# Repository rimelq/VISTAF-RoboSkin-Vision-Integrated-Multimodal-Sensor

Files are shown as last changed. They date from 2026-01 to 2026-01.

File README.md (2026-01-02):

# VISTAF RoboSkin: Vision-Integrated Multimodal Sensing

**_Robotics Semester Project, CREATE Lab, EPFL_**

A compact vision-based soft sensing skin that jointly estimates **force**, **shape**, and **temperature** from a single RGB camera view.

- **Student**: Rim El Qabli (Robotics MSc, EPFL)
- **Supervisor**: Benhui Dai (CREATE Lab, EPFL)
- **Professor**: Josie Hughes (CREATE Lab, EPFL)

For detailed methodology, fabrication procedures, and complete calibration results, see the full project report in the repo.

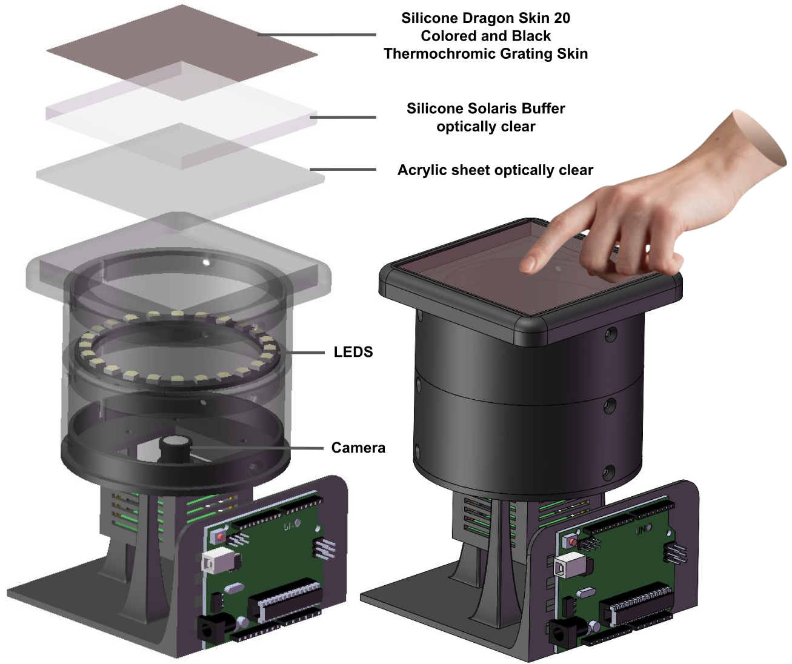
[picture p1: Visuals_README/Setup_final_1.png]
System Overview


## Overview

VISTAF RoboSkin uses a thin (0.6 mm) silicone grating with embedded thermochromic liquid crystal (TLC) pigments. The system combines:

- **Fourier Transform Profilometry (FTP)** for deformation/shape recovery
- **CIELAB-based regression** for temperature inference from TLC color changes
- **Two-stripe design** (colored + black TLC) for both high sensitivity and broad range coverage

This enables dense depth/force and temperature maps without electronics embedded in the skin.

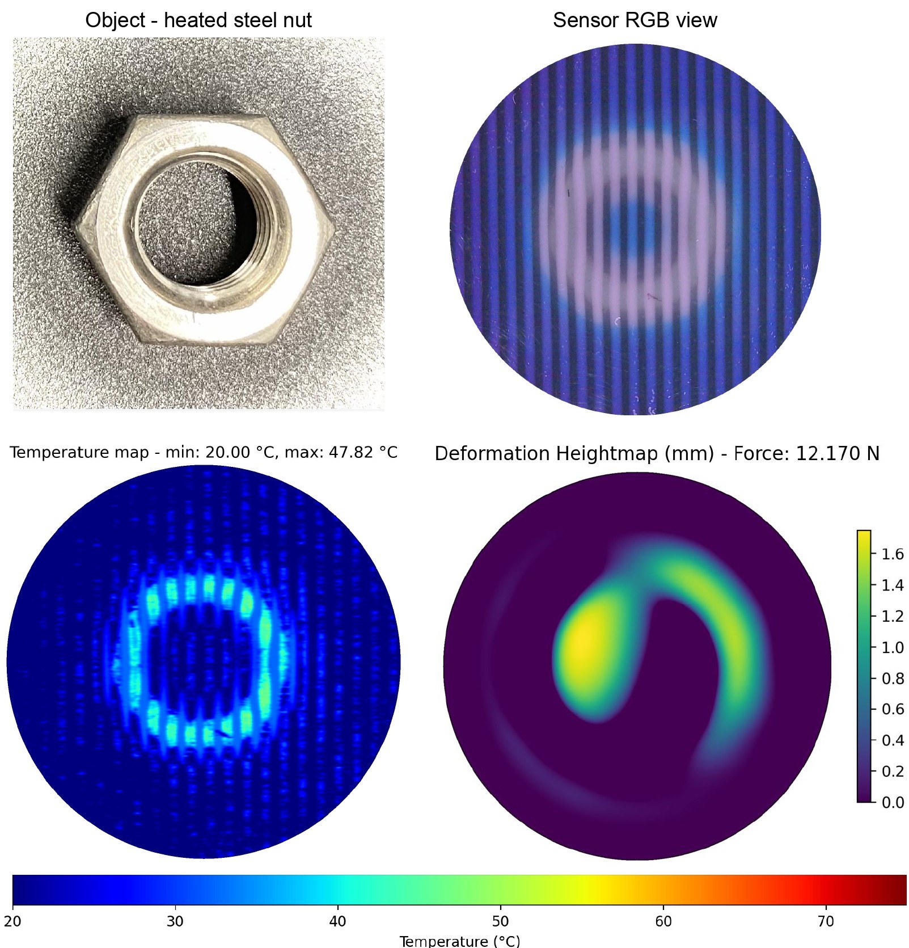
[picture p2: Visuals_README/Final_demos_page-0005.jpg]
Multimodal Demo

*Demo: A heated object pressed into the sensor reconstructs deformation (heightmap + force) and temperature (colormap).*

## How It Works

**Force/Shape Pipeline:**
1. FTP extracts phase differences between reference and deformed grating images
2. Phase → depth conversion via saturating calibration model
3. Depth integration → volume → force via exponential model

**Temperature Pipeline:**
1. CIELAB color feature extraction from TLC appearance
2. Stripe segmentation (colored vs black gratings)
3. Polynomial regression: CIELAB → Temperature

**Multimodal Integration:**
- Single camera view captures both grating deformation and TLC color
- Two stripe populations (colored: high sensitivity 20-33°C, black: broad range 10-75°C)
- Design preserves grayscale contrast for FTP while maximizing thermal information

## Performance Summary

| Module | Metric |
|---|---|
| Phase → Height | RMSE = 2.17 × 10⁻³ mm |
| Volume → Force | RMSE = 6.96 N |
| Temperature (Colored TLC) | RMSE = 0.44 °C |
| Temperature (Black TLC) | RMSE = 1.93 °C |

## Quick Start

### Installation
```bash
# Clone the repository
git clone https://github.com/YOUR_USERNAME/vistaf-roboskin.git
cd vistaf-roboskin

# Install dependencies
pip install numpy opencv-python matplotlib scikit-image scikit-learn scipy joblib
```

## Repository Structure
```
├── CAD/                              # CAD files for the setup
├── Code/                             # All source code (Python + notebooks)
│   ├── multimodal_sensor.py          # Main entry point (run multimodal inference)
│   ├── force_sensor.py               # Force sensing module
│   ├── temperature_sensor.py         # Temperature sensing module
│   ├── shape_ftp.py                  # FTP core pipeline
│   ├── phase_to_height.py            # Phase→height calibration
│   ├── height_to_force.py            # Height/volume→force calibration
│   ├── temperature_color_model.py    # Colored TLC temperature calibration
│   ├── temperature_black_model.py    # Black TLC temperature calibration
│   ├── pretest_25to30.py             # Temperature pretest (25→30 °C)
│   ├── pretest_30to31.py             # Temperature pretest (30→31 °C)
│   ├── michelson.ipynb               # Michelson contrast / TLC selection notebook
│   └── Arduino LED code/             # Arduino code for LED ring
├── Final_demos_images/               # Demo input images (used in report/README)
├── Force/                            # Force datasets + calibration outputs
├── Temperature/                      # Temperature datasets + calibration outputs
├── Multimodal_Sensor/                # Multimodal run outputs (session folders)
├── Visuals_README/                   # Figures used in README.md
├── camera_config.gpfl                # Camera configuration
├── Rim_El_Qabli_VISTAF_Report.pdf    # Full project report (PDF)
└── README.md                         # This file
```

### Running the Multimodal Sensor

Edit the paths at the top of `multimodal_sensor.py`:
```python
REFERENCE_IMAGE = "./Final_demos_images/FINAL_reference.jpg"
DEFORMED_IMAGE  = "./Final_demos_images/FINAL_ROUND_METAL.jpg"
OUTPUT_ROOT     = "./Multimodal_Sensor/run_output"

# Optional: Show interactive 3D heightmap window
SHOW_3D_HEIGHTMAP_INTERACTIVE = True
```

```bash
python multimodal_sensor.py
```

This will:
1. Load a reference image (no contact) and a deformed image (with contact/heating)
2. Run FTP to compute shape and force
3. Run temperature inference on the deformed image
4. Generate combined outputs with visualizations
5. Save results to `./Multimodal_Sensor/run_output/session_TIMESTAMP/`

### Outputs

After running, the session folder contains:
```
session_TIMESTAMP/
├── force_sensing/
│   └── ftp_run/                    # FTP heightmaps and debug figures
├── temperature_sensing/
│   ├── temperature_map_final_colormap.png
│   └── temperature_map_final.npy
├── combined_outputs/
│   ├── multimodal_summary.json     # Complete results + calibration metrics
│   ├── force_shape_heightmap.png   # Heightmap with force annotation
│   └── temp_*.png                  # Temperature visualizations
```

The `multimodal_summary.json` includes:
- Force estimate (N), volume (cm³), contact area (mm²), max depth (mm)
- Temperature statistics (mean, median, std, min/max)
- All calibration model equations and performance metrics

## Contact

- **Rim El Qabli**: rim.elqabli@epfl.ch
- **CREATE Lab**: https://www.epfl.ch/labs/create-lab/

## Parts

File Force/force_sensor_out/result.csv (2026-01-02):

reference_path | deformed_path | volume_cm3 | force_N | contact_area_mm2 | max_depth_mm | mm_per_px | estimated_grating_period_px | ftp_output_dir | force_model_type
./Force/FINAL_reference.jpg | ./Force/Final_demos/FFFFF_deformed.jpg | 0.15452928236587474 | 5.695553435044693 | 271.75127834004024 | 1.5117931365966797 | 0.030378426119953176 | 65.83619546657023 | ./Force/force_sensor_out/ftp_run | growth

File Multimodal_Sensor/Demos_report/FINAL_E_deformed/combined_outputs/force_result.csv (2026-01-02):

reference_path | deformed_path | volume_cm3 | force_N | contact_area_mm2 | max_depth_mm | mm_per_px | estimated_grating_period_px | ftp_output_dir | force_model_type
./Force/FINAL_reference.jpg | ./Final_demos_images/FINAL_E_deformed.jpg | 0.11378655442935222 | 3.2960528395288056 | 304.914771865451 | 1.1214957237243652 | 0.030378426119953176 | 65.83619546657023 | ./Multimodal_Sensor/run_output/session_20260101_195039/force_sensing/ftp_run | growth

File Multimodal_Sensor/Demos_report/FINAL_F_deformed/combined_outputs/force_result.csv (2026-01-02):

reference_path | deformed_path | volume_cm3 | force_N | contact_area_mm2 | max_depth_mm | mm_per_px | estimated_grating_period_px | ftp_output_dir | force_model_type
./Force/FINAL_reference.jpg | ./Final_demos_images/FINAL_F_deformed.jpg | 0.15452928236587474 | 5.695553435044693 | 271.75127834004024 | 1.5117931365966797 | 0.030378426119953176 | 65.83619546657023 | ./Multimodal_Sensor/run_output/session_20260101_194957/force_sensing/ftp_run | growth

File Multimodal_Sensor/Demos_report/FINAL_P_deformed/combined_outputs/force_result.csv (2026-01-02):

reference_path | deformed_path | volume_cm3 | force_N | contact_area_mm2 | max_depth_mm | mm_per_px | estimated_grating_period_px | ftp_output_dir | force_model_type
./Force/FINAL_reference.jpg | ./Final_demos_images/FINAL_P_deformed.jpg | 0.09709512564796216 | 2.557286790972208 | 327.0289970254414 | 0.9775881767272949 | 0.030378426119953176 | 65.83619546657023 | ./Multimodal_Sensor/run_output/session_20260101_194609/force_sensing/ftp_run | growth

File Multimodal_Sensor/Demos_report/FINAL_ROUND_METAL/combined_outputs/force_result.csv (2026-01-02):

reference_path | deformed_path | volume_cm3 | force_N | contact_area_mm2 | max_depth_mm | mm_per_px | estimated_grating_period_px | ftp_output_dir | force_model_type
./Force/FINAL_reference.jpg | ./Final_demos_images/FINAL_ROUND_METAL.jpg | 0.21950436806104176 | 12.169759841071881 | 343.2434499762836 | 1.7482119798660278 | 0.030378426119953176 | 65.83619546657023 | ./Multimodal_Sensor/run_output/session_20260101_195157/force_sensing/ftp_run | growth

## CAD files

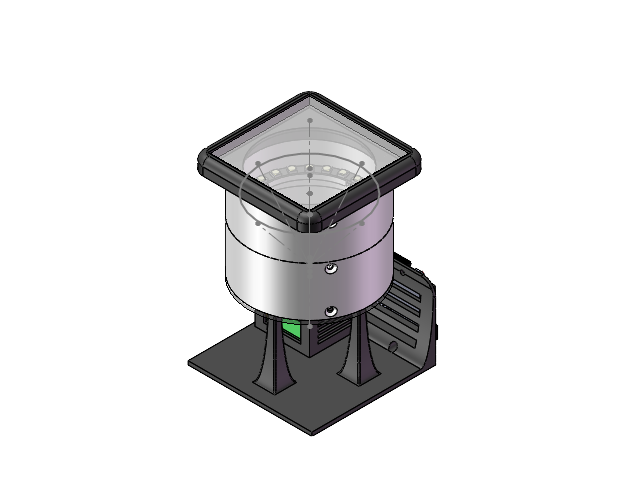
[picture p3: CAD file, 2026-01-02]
CAD/v2-setup.SLDASM
v2-top base
v2-middle holder
v2-led light ring
v2-bottom base
camera
arcylic layer
transparent elastic layer
v2-adjust base
v2-camera connect
test support
arduino uno

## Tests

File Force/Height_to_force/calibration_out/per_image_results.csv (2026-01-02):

file | force_N | volume_cm3 | contact_area_mm2 | max_depth_mm | mm_per_px | estimated_grating_period_px | ftp_output_dir
sphere-1.jpg | 0.5 | 0.013897318468323634 | 205.22311025659033 | 0.2618858516216278 | 0.030378426119953176 | 65.83619546657023 | ./Force/Height_to_force/calibration_out/ftp_runs/001_sphere-1_F0.5N
sphere-2.jpg | 0.5 | 0.015697668452302027 | 206.68121131876055 | 0.22853468358516693 | 0.030378426119953176 | 65.83619546657023 | ./Force/Height_to_force/calibration_out/ftp_runs/002_sphere-2_F0.5N
sphere-3.jpg | 0.5 | 0.010988610885390073 | 161.01034836575937 | 0.20464380085468292 | 0.030378426119953176 | 65.83619546657023 | ./Force/Height_to_force/calibration_out/ftp_runs/003_sphere-3_F0.5N
sphere-4.jpg | 0.5 | 0.019896585310867573 | 267.0484409901546 | 0.25566136837005615 | 0.030378426119953176 | 65.83619546657023 | ./Force/Height_to_force/calibration_out/ftp_runs/004_sphere-4_F0.5N
sphere-5.jpg | 0.5 | 0.010413515682411756 | 161.8335294717441 | 0.16386406123638153 | 0.030378426119953176 | 65.83619546657023 | ./Force/Height_to_force/calibration_out/ftp_runs/005_sphere-5_F0.5N
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

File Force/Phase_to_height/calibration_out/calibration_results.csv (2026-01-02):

file | depth_mm | min_height_unitless | min_x | min_y | heightmap_figure
Height_0.5mm_deformed.jpg | 1.90935 | -0.5882240533828735 | 703 | 514 | Height_0.5mm_deformed/heightmap.png
Height_1mm_deformed.jpg | 1.9477 | -0.6571923494338989 | 607 | 524 | Height_1mm_deformed/heightmap.png
Height_1.5mm_deformed.jpg | 2.01821 | -0.8232495188713074 | 729 | 537 | Height_1.5mm_deformed/heightmap.png
Height_2mm_deformed.jpg | 2.07255 | -1.2602728605270386 | 722 | 588 | Height_2mm_deformed/heightmap.png

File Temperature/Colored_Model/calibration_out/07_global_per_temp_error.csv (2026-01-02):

label | T_true | n_frames | mean_pred | mean_err | mae | rmse | max_abs_err
global | 20.0 | 10 | 20.186666666666664 | 0.18666666666666706 | 0.18666666666666706 | 0.3412395704551935 | 0.6666666666666679
global | 21.0 | 10 | 20.813333333333333 | -0.186666666666666 | 0.186666666666666 | 0.2649947588580229 | 0.3999999999999986
global | 22.0 | 10 | 22.25 | 0.25 | 0.25 | 0.3535533905932738 | 0.5
global | 23.0 | 10 | 23.375 | 0.375 | 0.875 | 0.9519716382329886 | 1.25
global | 24.0 | 10 | 24.25 | 0.25 | 0.25 | 0.25 | 0.25
global | 25.0 | 10 | 25.5 | 0.5 | 0.5 | 0.7071067811865476 | 1.0
global | 26.0 | 10 | 25.375 | -0.625 | 1.125 | 1.286953767623375 | 1.75
global | 27.0 | 10 | 26.25 | -0.75 | 0.75 | 0.7905694150420949 | 1.0
global | 28.0 | 10 | 28.0 | 0.0 | 0.0 | 0.0 | 0.0
global | 29.0 | 10 | 29.800000000000004 | 0.8000000000000007 | 0.8000000000000007 | 1.1313708498984771 | 1.6000000000000014
global | 30.0 | 10 | 30.300000000000004 | 0.3000000000000007 | 0.3000000000000007 | 0.4242640687119295 | 0.6000000000000014
global | 31.0 | 10 | 30.600000000000005 | -0.3999999999999986 | 0.3999999999999986 | 0.3999999999999986 | 0.3999999999999986
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

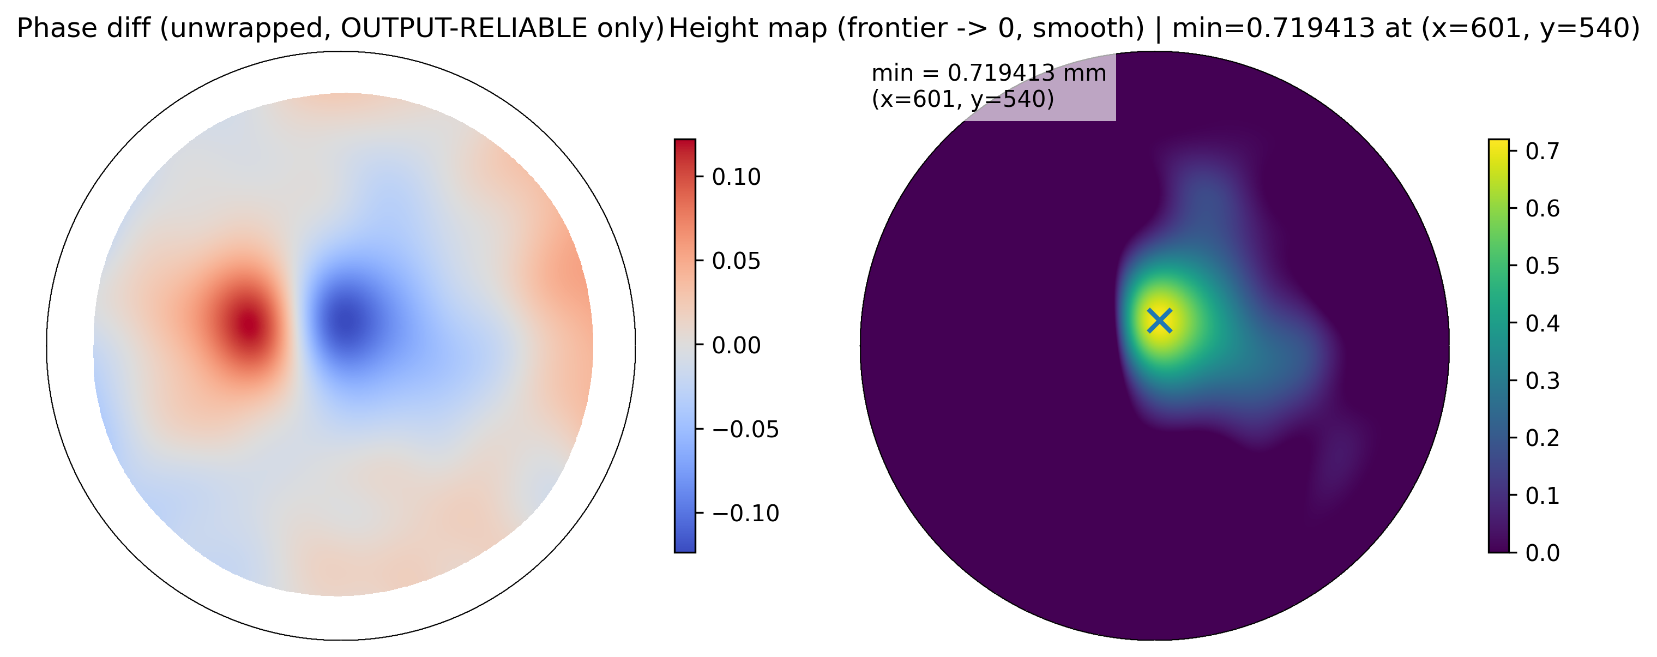
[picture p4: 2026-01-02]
Force/Height_to_force/calibration_out/ftp_runs/008_sphere-8_F1N/07_phase_and_height_FINAL_SMOOTH_ROI.png

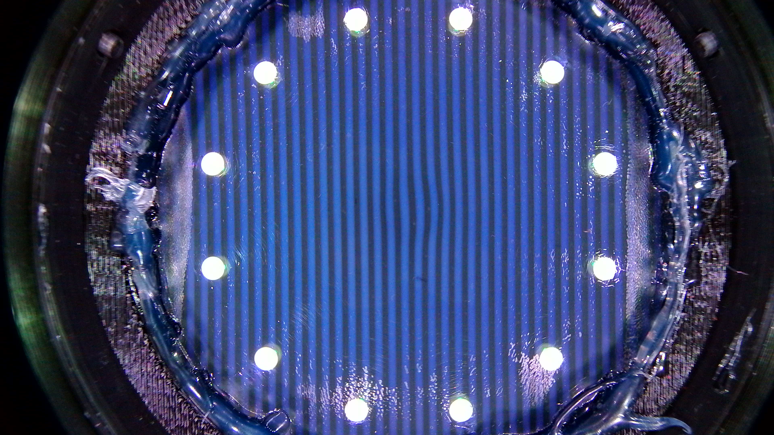
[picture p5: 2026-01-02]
Force/Height_to_force/calibration_out/ftp_runs/039_sphere-39_F10N/sphere-39.jpg

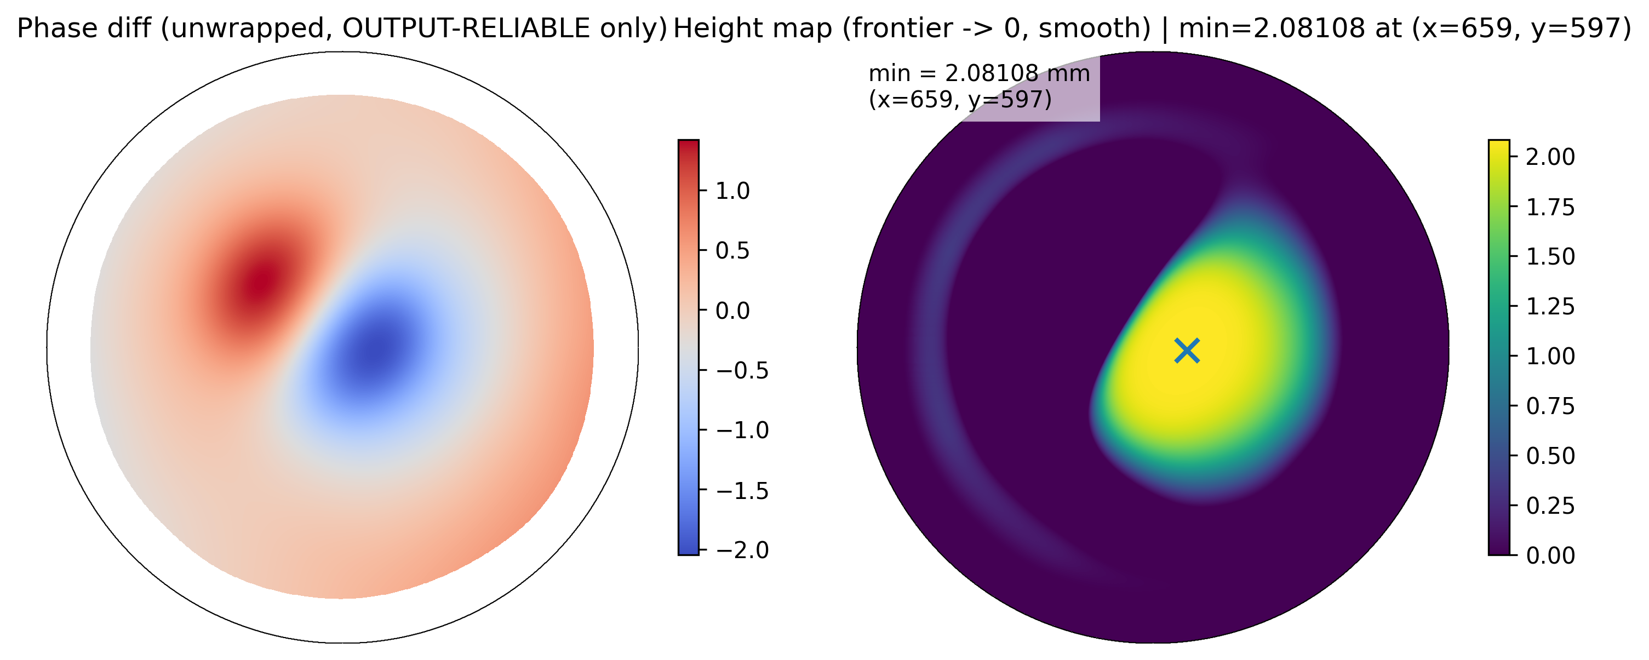
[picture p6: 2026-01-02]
Force/Height_to_force/calibration_out/ftp_runs/052_sphere-52_F25N/07_phase_and_height_FINAL_SMOOTH_ROI.png

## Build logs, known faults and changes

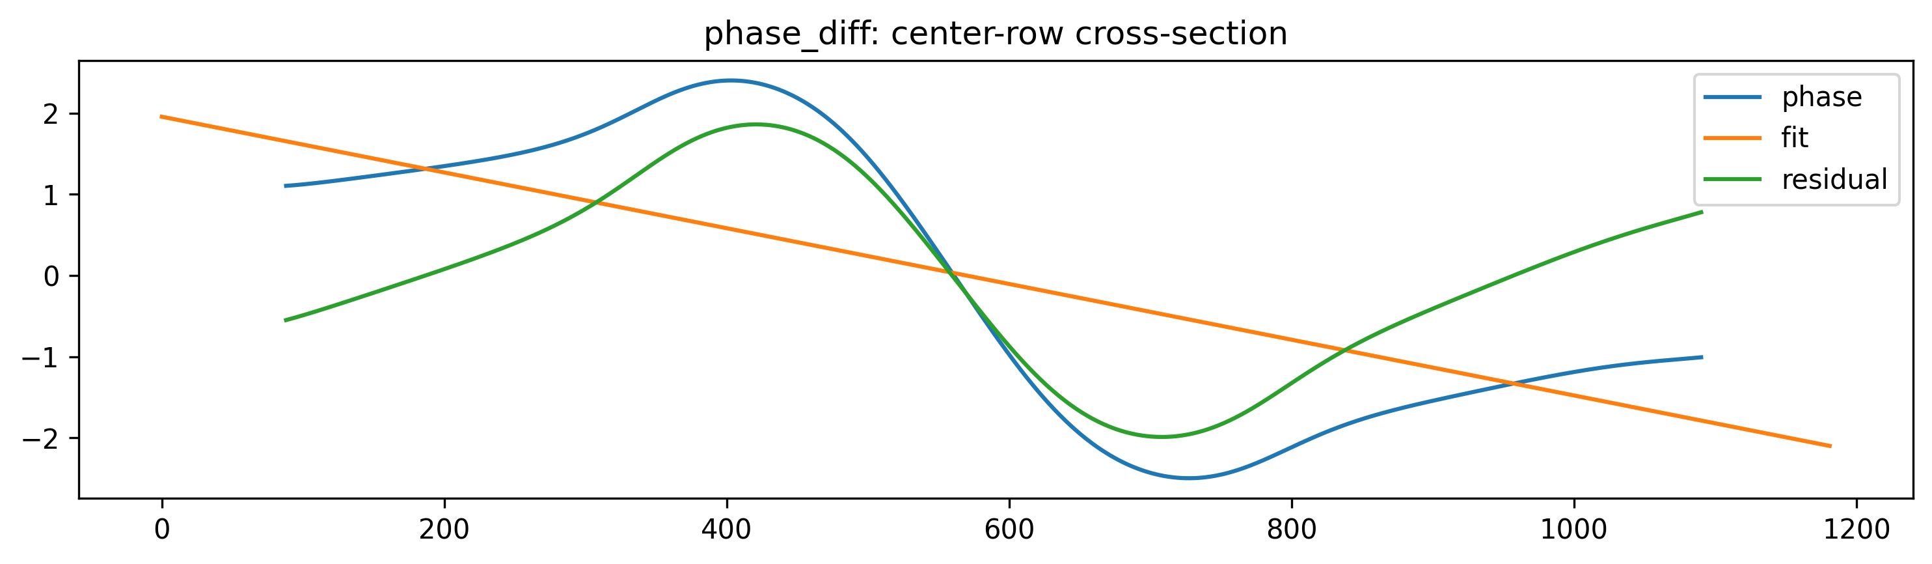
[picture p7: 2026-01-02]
Force/Height_to_force/calibration_out/ftp_runs/075_sphere-75_F45N/DEBUG_ramp_cross_phase_diff.png

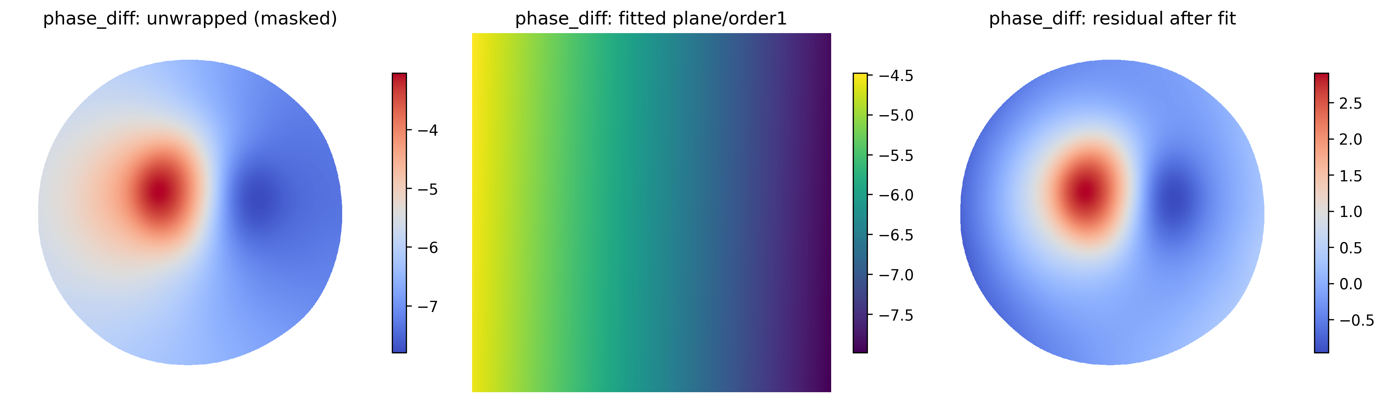
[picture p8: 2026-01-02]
Force/Height_to_force/calibration_out/ftp_runs/067_sphere-67_F40N/DEBUG_ramp_phase_diff.png

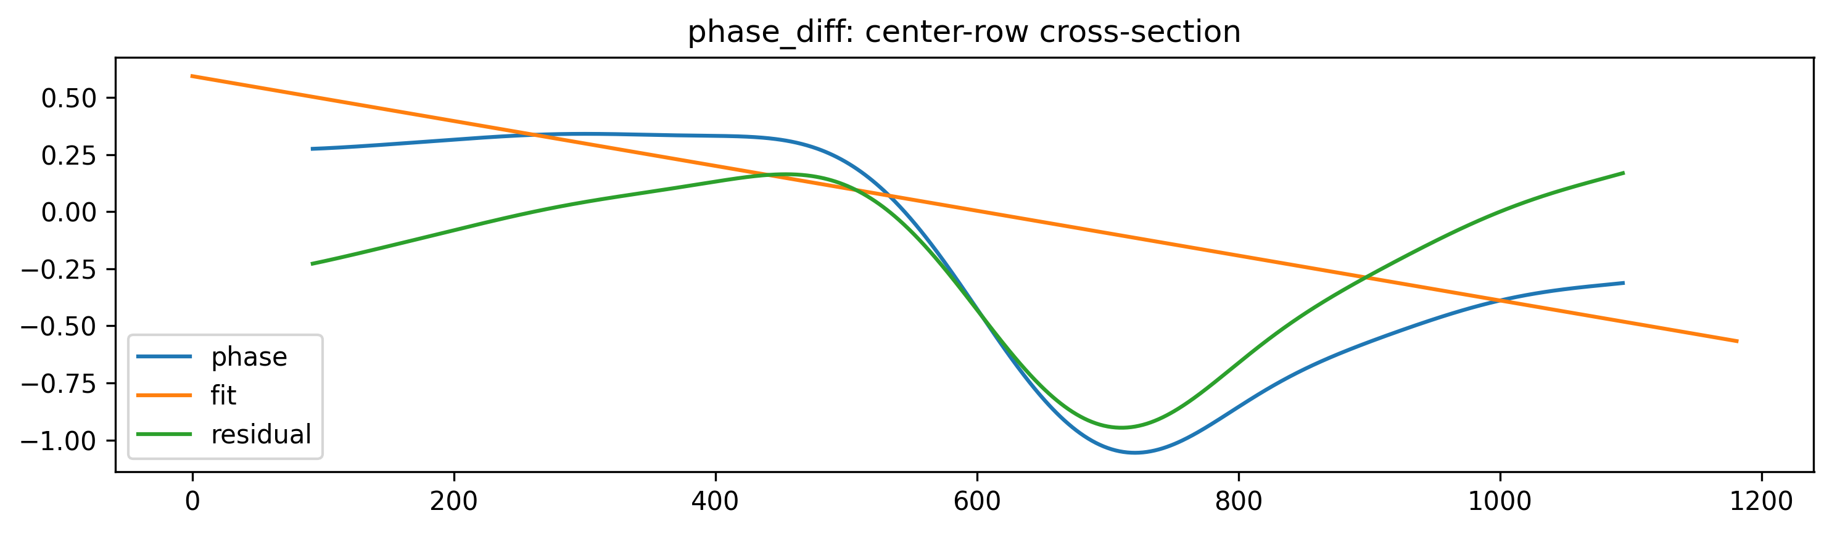
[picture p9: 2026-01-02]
Force/Height_to_force/calibration_out/ftp_runs/037_sphere-37_F10N/DEBUG_ramp_cross_phase_diff.png

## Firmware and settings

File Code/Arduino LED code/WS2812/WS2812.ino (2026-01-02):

#include <Adafruit_NeoPixel.h>

#define LED_PIN     6
#define NUMPIXELS   24
#define BRIGHTNESS  30

Adafruit_NeoPixel strip(NUMPIXELS, LED_PIN, NEO_GRB + NEO_KHZ800);

bool ledsOn = false;

void setup() {
  Serial.begin(9600); // Start serial communication
  strip.begin();
  strip.setBrightness(BRIGHTNESS);
  strip.clear();
  strip.show();

  Serial.println("Type 'on' to turn LEDs on, 'off' to turn them off.");
}

void loop() {
  if (Serial.available() > 0) {
    String command = Serial.readStringUntil('\n');
    command.trim(); 

    if (command == "on") {
      ledsOn = true;

      for (int i = 1; i < NUMPIXELS; i += 2) {
        strip.setPixelColor(i, strip.Color(210, 245, 125));
      }

      strip.show();
      Serial.println("LEDs turned ON");
    } else if (command == "off") {
      ledsOn = false;
      strip.clear();
      strip.show();
      Serial.println("LEDs turned OFF");
    } else {
      Serial.println("Unknown command. Type 'on' or 'off'.");
    }
  }
}
